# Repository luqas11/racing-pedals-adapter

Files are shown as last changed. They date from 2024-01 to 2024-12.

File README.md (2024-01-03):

# racing-pedals-adapter

This project is a **custom adapter** for an old **PC racing wheel** that has two pedals and a steering wheel with some buttons. Pedals are connected to the wheel through a special connector, and the wheel is connected to the PC through an USB connector.  

For some reason, the wheel isn't correctly broadcasting the pedals position to the PC, so this adapter aims to provide a direct connection between the pedals and the PC, bypassing the malfunctioning wheel. The connection goes through an **ATmega32U4** based **Arduino** board, that sends the pedals potentiometers signals to the PC as PC joystick axes. Also, a small 3D printed case keeps the board and the cables safe.

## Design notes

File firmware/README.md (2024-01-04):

# Firmware

### How this works
The [Arduino Joystick Library](https://github.com/MHeironimus/ArduinoJoystickLibrary) allows an **ATMega32u4** board to be recognized by the PC as a PC Joystick, and providas an API that allows the Joystick buttons and axes to be pressed and moved from the board. Pedals potentiometers values come from the pedals cables to the analog inputs, and the firmware constrains and maps this values to the library acceptable ranges. 

### Potentiometer linearization
Since the potentiometers are logarithmic, their raw values vary logarithmically while pressing the pedals. To linearize them, the potentiometer curve must by measured and adjusted by some function. Applying the inverse of that function to the raw values will give linear readings.  

Taking 8 equally distant points form the pedal press range, the measured raw values are the following:
| Point  | Raw value |
| --- | --- |
| 0  | 53 |
| 1  | 62 |
| 2  | 80 |
| 3  | 110 |
| 4  | 210 |
| 5  | 550 |
| 6  | 1010  |
| 7  | 1010  |
| 8  | 1010  |  

Wich can be reasonably adjusted by the curve:  
`f(x) = 3e^x + 50`  

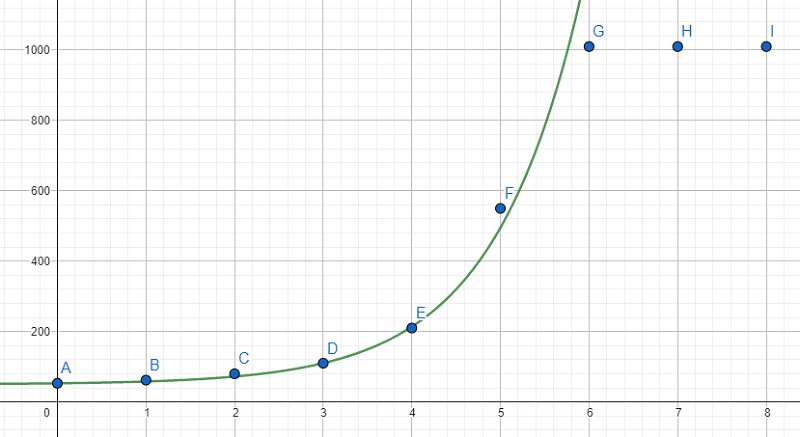
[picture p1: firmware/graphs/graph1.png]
Potentiometer adjustment curve
  

Applying the inverse of that function to the raw values gives a perfect linearization, but very out of scale:  
`f(x) = log(x - 50) - ln(3)`  

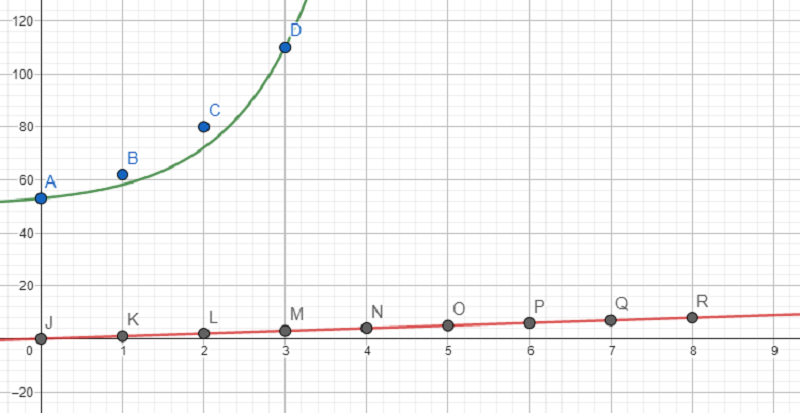
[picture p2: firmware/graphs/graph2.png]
Potentiometer curve linearization
  

By correcting some constants, a better scaled linearization function can be defined:  
`f(x) = log(x - 45) * 50`  

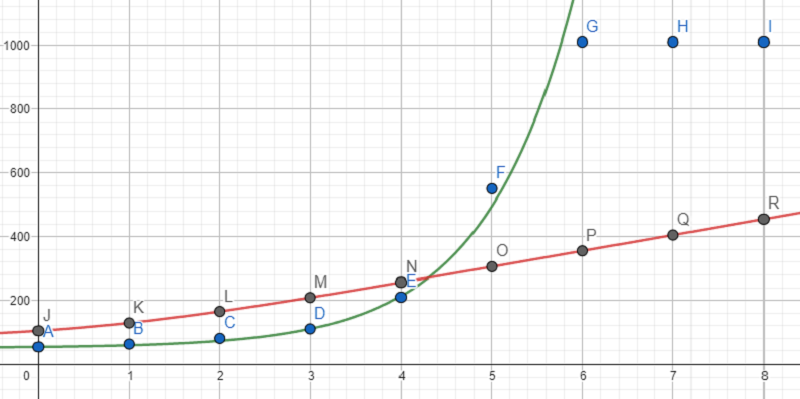
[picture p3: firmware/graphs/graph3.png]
Potentiometer curve linearization correction
  

The last one is the function that the firmwate actually uses. 

Another way to see the last function and it's constants meanings is the following:  
`linearizedValue = log(rawValue - minimumValue) * slope`  
Where:
-  `linearizedValue` is the value after the linearization
-  `rawValue` is the potentiometer raw reading
-  `minimumValue` is the raw value of the potentiometer when the pedal is not pressed (that's necessary to avoid taking the logarithm of a negative value)
-  `slope` is the slope of the linearized line (a higher value will give a better signal resolution, and a lower value will give lower aproximation errors)

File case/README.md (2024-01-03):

# Case

Small 3D printable design that holds the board and the pedals cable, and exposes the board USB port to allow an easy connection.

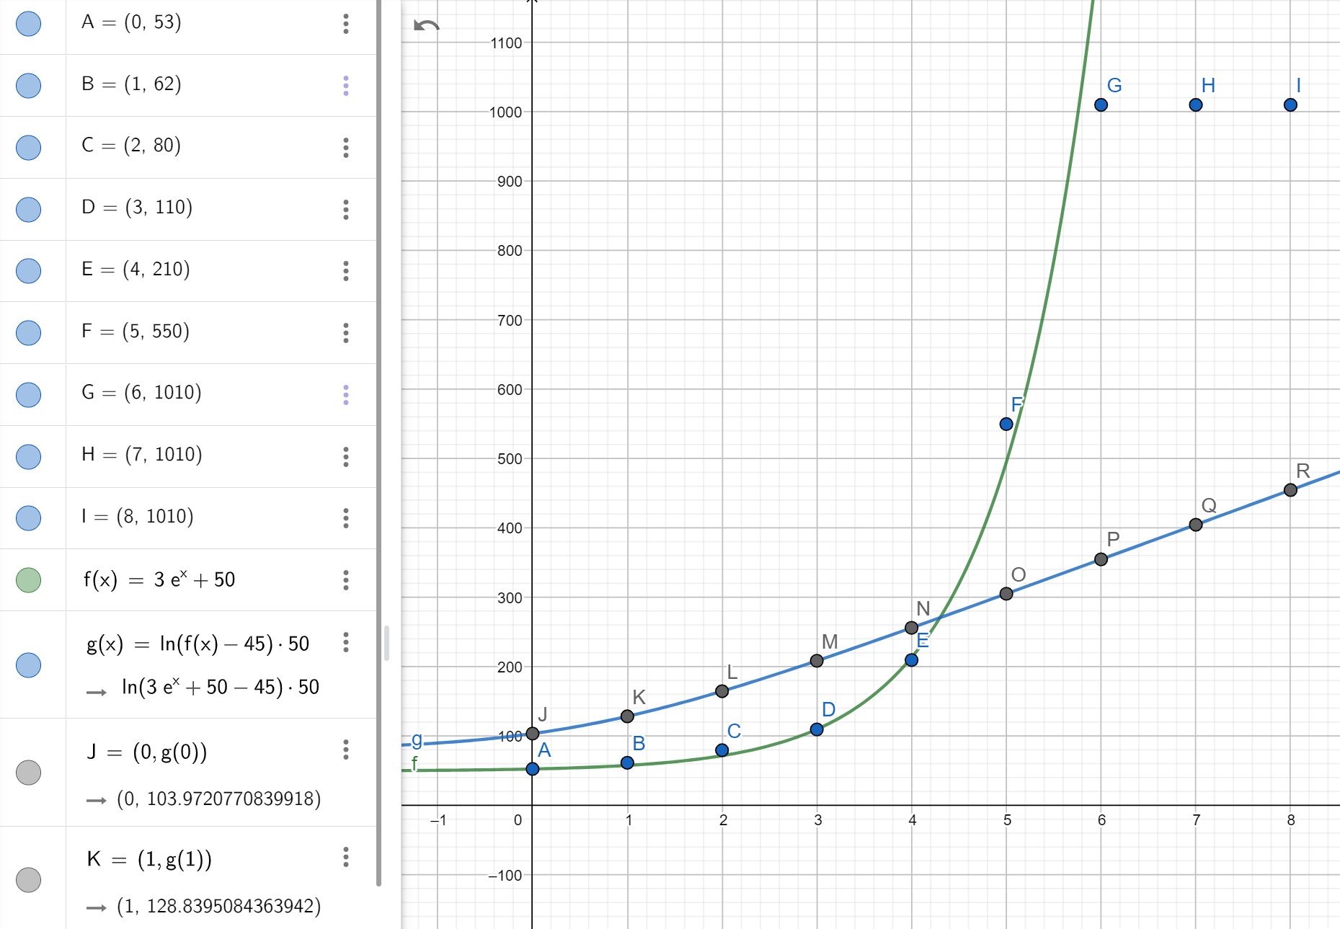
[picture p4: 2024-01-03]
firmware/potentiometer_curve.png

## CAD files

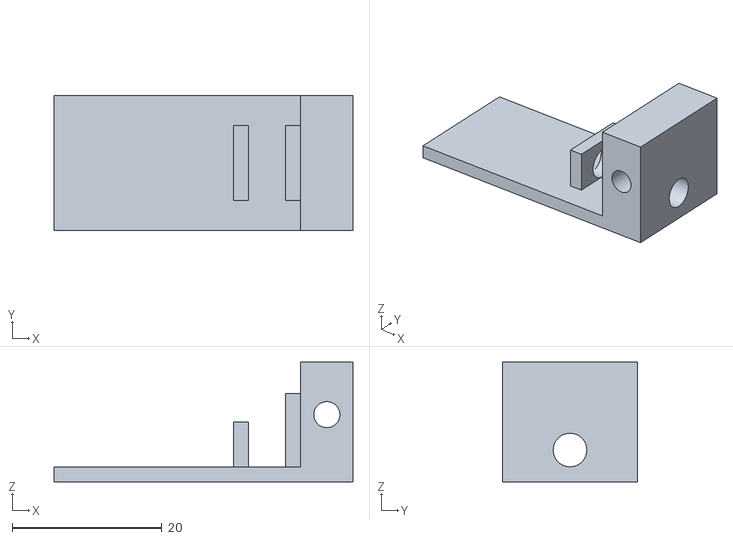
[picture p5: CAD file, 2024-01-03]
case/cover.stl
40.0 x 18.0 x 16.0

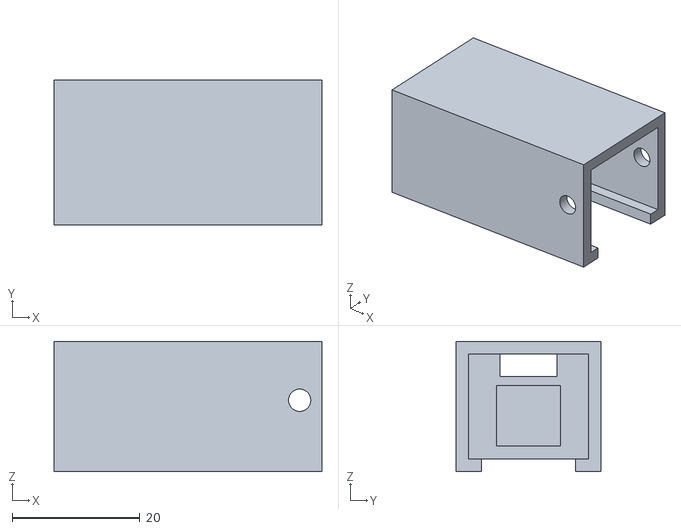
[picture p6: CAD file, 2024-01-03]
case/base.stl
42.0 x 22.8 x 20.4

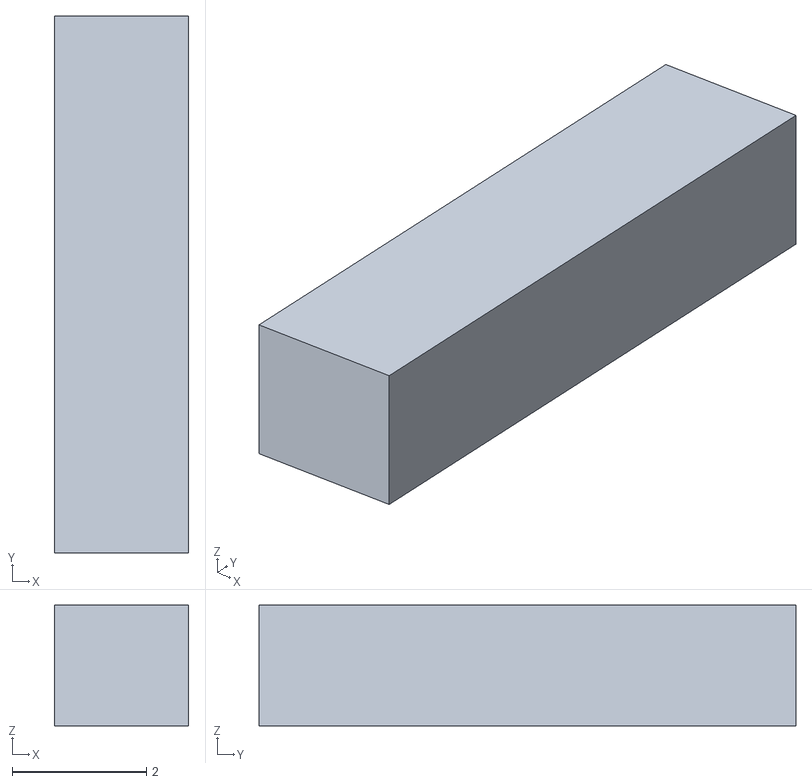
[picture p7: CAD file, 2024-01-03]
case/support.stl
2.00 x 8.00 x 1.80

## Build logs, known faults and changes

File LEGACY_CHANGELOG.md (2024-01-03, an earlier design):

# Pedalera Rosvi

## Versión 1.0 (26/3/2022)  
*Probado en PC en conjunto con el volante.*
- Sketch para enviar la señal linealizada del potenciómetro a la PC.
- Modelos 3D de la caja para contener el Arduino.

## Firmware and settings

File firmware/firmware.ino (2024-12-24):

#include <Joystick.h>

// Joystick object
Joystick_ Joystick;
// If true, disables the joystick and sends the input data to the serial monitor instead
const bool DEBUG_MODE = false;

void setup() {
  // Initialize objects
  if (DEBUG_MODE) {
    Serial.begin(9600);
  } else {
    Joystick.begin();
  }
}

void loop() {
  // Read the analog inputs and map the raw values to acceptable values for the Joystick object
  int accelerator = analogRead(A0);
  accelerator = log(accelerator - 45) * 50;
  accelerator = constrain(accelerator, 120, 330);
  accelerator = map(accelerator, 120, 330, 0, 1023);

  int brake = analogRead(A2);
  brake = log(brake - 45) * 50;
  brake = constrain(brake, 120, 330);
  brake = map(brake, 120, 330, 0, 1023);

  if (DEBUG_MODE) {
    // Print the raw input values in the serial monitor
    Serial.println();
    Serial.println("Raw analog inputs values:");
    Serial.println("Accelerator: " + (String)(analogRead(A0)));
    Serial.println("Brake: " + (String)(analogRead(A2)));
    delay(200);
  } else {
    // Set the mapped input values to the Joystick axes
    Joystick.setRxAxis(accelerator);
    Joystick.setRyAxis(brake);
  }
}

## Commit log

2024-01-03 Add first project version
    [base.stl, cover.stl, support.stl]
2024-12-24 Remove VSCode Arduino extension configuration files
2024-12-24 Format firmware sketch with the Arduino IDE 2 auto formatter
